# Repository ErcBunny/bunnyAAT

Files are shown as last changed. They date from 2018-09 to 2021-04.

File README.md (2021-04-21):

# bunnyAAT v0.0.2b

* Warning: a senior high school level project.

## PREFACE

* I know it is strange that this repo starts with v0.0.2b. Well, the earlier versions can be found at tieba. And if you read Chinese you'll know more details about this project, which is not necessary at all since the best part (so far) is posted here at github.

## HARDWARE SETUP

* In "hardware" folder you can find autocad blueprints (.dwg) and schematic diagrames.
  
* Read the schematic diagrams and you will know what boards and sensors to buy.
  
* "3mm.dwg" illustrates additional parts needed to complete the structure of the antenna tracker and also the payload adapter for blacksheep  quadcopter airframe, which is shown in "blacksheep.dwg".
  
* "adapter.dwg" is only useful if you want to use the 23dbi MFD antenna. Otherwise you can simply glue your antenna to the moving part.
  
* "base.dwg" shows you what bunnyAAT looks like. Most of its parts are bought online. One possible version of the base can be found here: https://item.taobao.com/item.htm?spm=a1z09.2.0.0.28812e8dhvkkIb&id=37631042726&_u=a2ndlmbi166b.
  
* Also, it is recommended to cover the baro_sensor with a sponge and a reflective surface at the top. By doing this, we can increase sensing accuracy (but only a bit).

## ABOUT SOFTWARE

* There are two apps for android. One of the two is magvar.apk. This app connects automatically to https://www.ngdc.noaa.gov/geomag-web/#declination. By enabling the positioning service the app will return the declination value of your location. The other one is terminal.apk. It is a bluetooth terminal with macro buttons which displays aircraft status and voltage of batteries.
  
* "mwc.ino" should be uploaded into the mwc flight controller board (make sure that your flight controller uses BMP180 and MPU6050, otherwise you need to modify the code). "servo.ino" should be uploaded into another pro mini board. In order to upload sketches you may need the FTDI USB to TTL tool and corresponding driver.
  
* "uno.ino" is for the uno board installed on your aircraft.

## CONFIGURATION

* Change gps refresh rate to 5hz or higher.
  
* Edit macro buttons in the terminal app. '0' must be set as "continue" and '_local declination value_' is recommended to be set as "default". 
  
* Turn your tracker into debug mode by uncommenting the the first line of "mwc.ino" and put your aircraft at the same height as the antenna. Follow the instructions. When you reach the stage of calibrating the mag_sensor, the tracker should spin clockwise. If not, swap the values of LEFT and RIGHT in line 2 and 4. And if the pan servo doesn't stop, modify the STOP value too. The debug mode returns two statements "#define offAlt _value_" and "#define K _value_". Modify the values in line 5 and 6 then comment line 1 and upload. Now you are good to go.
  
* When the the aircraft and AAT are exposed to direct sunlight, the baro_sensors are very likely to be affected. That is, the value returned in debug mode is not accurate anymore. You need to redo debugging or adjust the offAlt value after estimating the error.
  
* The last thing. You may notice that the V_air and V_gnd is really off the track. Therefore, in "mwc.ino" and "uno.ino" you can find "#define offV", which enables you to calibrate the value by hand. For example, if V_gnd is 3.7 displayed in terminal, while its real value is 4.0, then I'll enter "#define offV 0.3 (4.0 - 3.7)".

## CREDITS

* Libraries are very helpful. I saved a lot of time by using them. I'd like to thank contributors who uploaded their libraries.
  
* I don't quite understand how a kalman filter works (just for now), so the code for this part is written by Similar_Fair. Click the link below for more information: https://blog.csdn.net/sunhaobo1996/article/details/53861752.

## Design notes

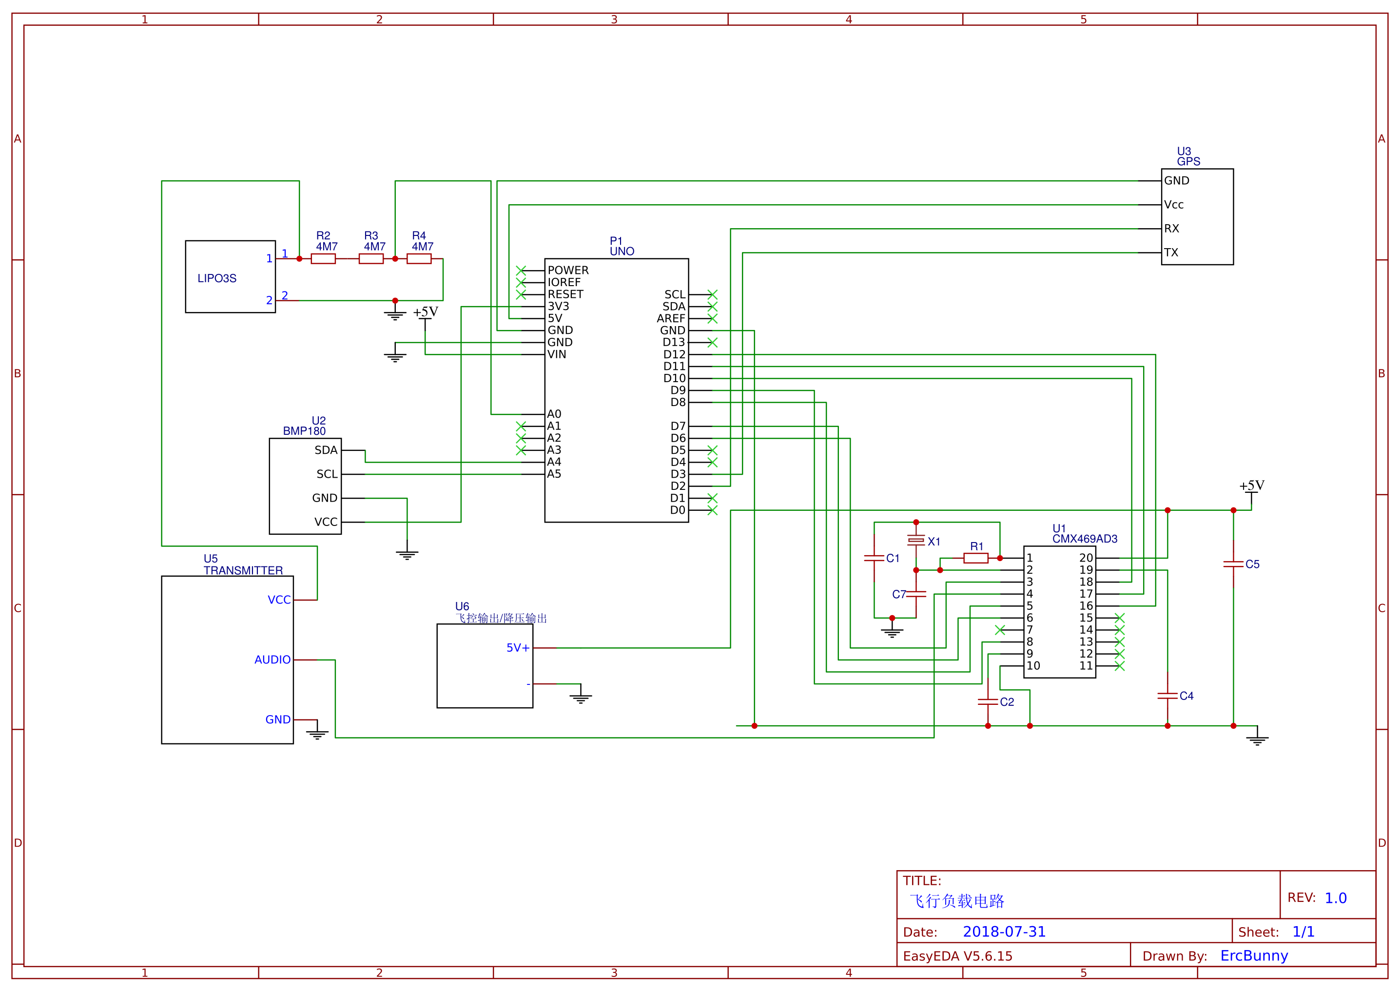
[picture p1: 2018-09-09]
hardware/scheme/aircraft.png

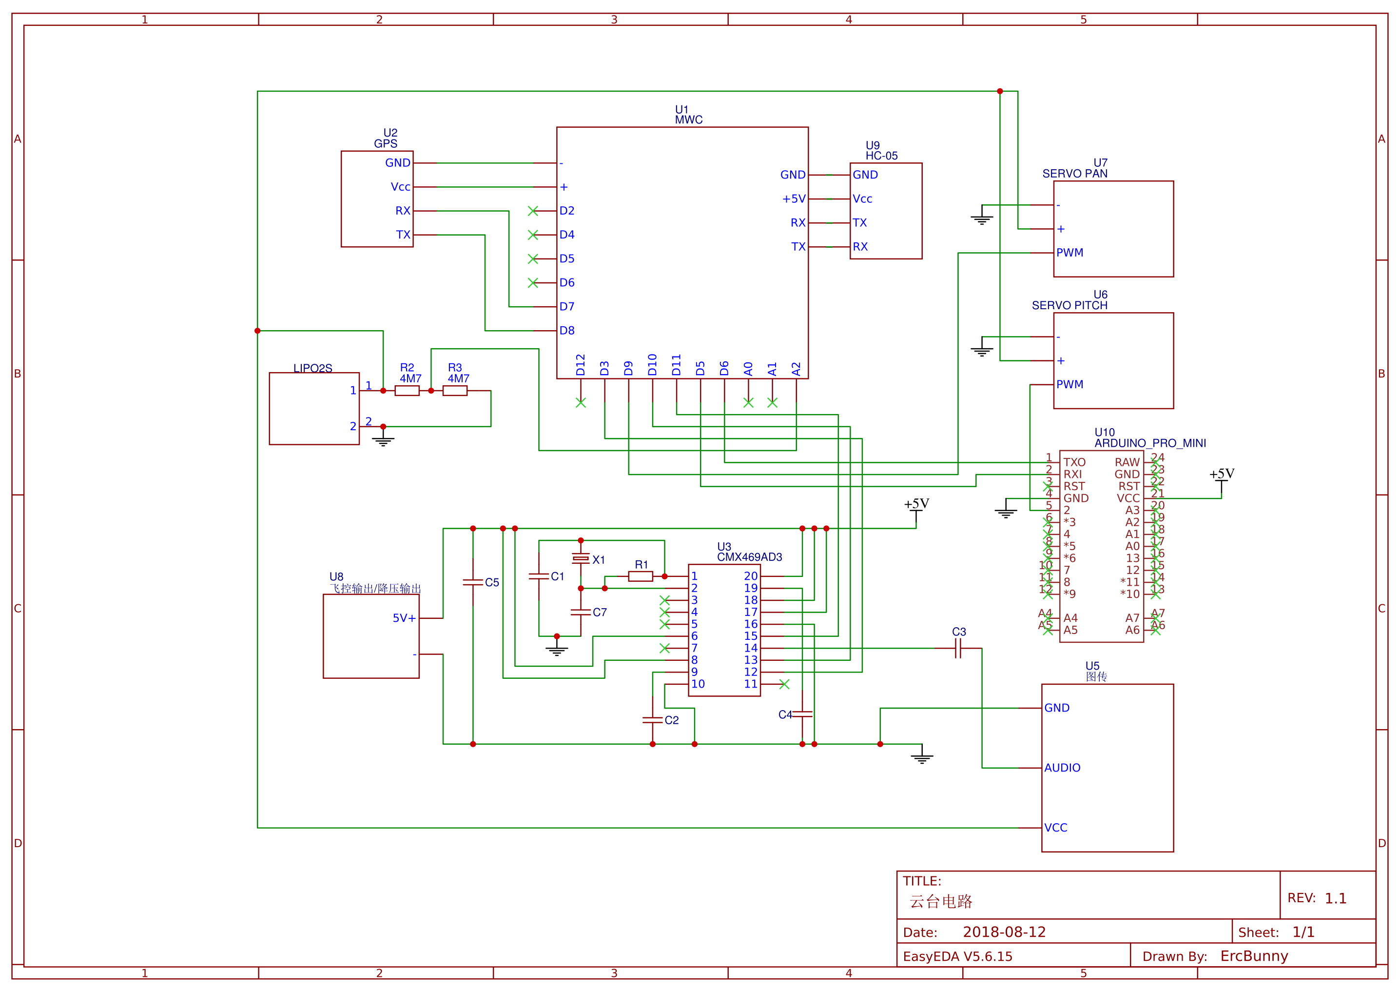
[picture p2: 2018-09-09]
hardware/scheme/aat.png

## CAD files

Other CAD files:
hardware/frame/3mm.dwg
hardware/frame/blacksheep.dwg
hardware/frame/adapter.dwg

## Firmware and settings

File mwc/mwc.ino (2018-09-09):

//#define DEBUG
#define LEFT 180
#define STOP 90
#define RIGHT 0
#define offALT -31.8
#define K 5.5
#define offV 0.11

#include <SoftwareSerial.h>
#include <Wire.h>
#include <Servo.h>
#include <TinyGPS++.h>
#include <HMC5883L.h>
#include <MPU6050.h>
#include <SFE_BMP180.h>

SoftwareSerial gpsCom(8, 7);              //rx,tx
SoftwareSerial pitchCom(6, 5);
TinyGPSPlus gps;
Servo pan;
HMC5883L compass;
MPU6050 mpu;
SFE_BMP180 baro;

int i, m;
int rxdata[135] = {};
int Buffer[120] = {};
char script[29] = {};
float offX, offY, minX, maxX, minY, maxY;
float declination, vt, alt, aim, dst, bat, heading; //angle int->double
double pr, la, lg, angle, baseline;

void setup() {
  Serial.begin(115200);                  //initiate serial com
#ifndef DEBUG
  Serial.println(F("Antenna tracker version 0.0.2 beta by ErcBunny."));  //print info
  Serial.println(F("Initializing sensors..."));
#else
  Serial.println(F("Debug mode. Reading baseline pressure..."));
  Serial.println();
#endif
  mpu.begin(MPU6050_SCALE_2000DPS, MPU6050_RANGE_2G);
  mpu.setI2CMasterModeEnabled(false);
  mpu.setI2CBypassEnabled(true);
  mpu.setSleepEnabled(false);
  compass.begin();
  compass.setRange(HMC5883L_RANGE_1_3GA);
  compass.setMeasurementMode(HMC5883L_CONTINOUS);
  compass.setDataRate(HMC5883L_DATARATE_30HZ);
  compass.setSamples(HMC5883L_SAMPLES_8);
  baro.begin();                                           //setup sensors
  double Pressure, sum = 0;
  for(i = 0; i < 300; i++){
    Pressure = getPressure();
    sum += Pressure;
  }
  baseline = sum / 300;
  Serial.print(F("Done. Baseline pressure (in mb) is "));
  Serial.println(baseline);
  Serial.print(F("Enter declination value (E+|W-): "));   //wait for input
  char a[7] = { 0 };
  i = 0;
  while (1) {
    if (Serial.available()) {
      a[i] = Serial.read();
      i++;
      if (a[i - 1] == 10) {
        break;
      }
    }
  }
  declination = atof(a);
  Serial.println(declination);
  Serial.println(F("Touch continue to start calibration.")); //wait for command
  while (1) {
    if (Serial.available()) {
      i = Serial.read();
      if (i == '0') {
        break;
      }
    }
  }
  calibrate();
  delay(500);
  Serial.println(F("Successful."));
#ifndef DEBUG
  gpsCom.begin(57600);
  Serial.println(F("Waiting for positioning service..."));  //wait till gps is ready
  i = 0;
  while (i == 0) {
    while (gpsCom.available() > 0) {
      if (gps.encode(gpsCom.read()) && gps.location.isUpdated()) {
        i = 1;
      }
    }
  }
  gpsCom.end();
#endif
  pinMode(3, INPUT);        //CLKED DATA 12
  pinMode(10, INPUT);       //CARRIER DETECT 13
  pinMode(11, INPUT);       //RXSYNC 15
#ifndef DEBUG
  Serial.println(F("System setup complete. Touch continue to start using."));
  while (1) {
    if (Serial.available()) {
      i = Serial.read();
      if (i == '0') {
        Serial.println(F("Waiting for data..."));
        break;
      }
    }
  }
  Serial.end();
#endif
}

void loop() {
#ifndef DEBUG
  while (digitalRead(10) == HIGH);
  while (digitalRead(10) == LOW);  //skip incomplete data
  input();                      //store data in rxdata[135]
  check();                      //crc check
  if (m == 0) {
    btod();                     //bin to dec
    extract();                  //store data in variable after checking domain
    calculate();                //calculate dst angle etc.
    output();                   //print info and drive servos
  }
#else
  Serial.begin(115200);
  Serial.println(F("Make sure the aircraft is connected and continue..."));
  while (1) {
    if (Serial.available()) {
      i = Serial.read();
      if (i == '0') {
        break;
      }
    }
  }
  Serial.println(F("Connecting..."));
  Serial.end();
  float sum_alt = 0;
  for (int j = 0; j < 100; j++) {
    while (digitalRead(10) == HIGH);
    while (digitalRead(10) == LOW);
    input();
    check();
    if (m == 0) {
      btod();
      extract();
      calculate();
    }
    sum_alt = alt + sum_alt;                       //sample offalt value 100 times and calculate average
    Serial.begin(115200);
    Serial.print(j);
    Serial.println(F("%"));
    Serial.end();
  }
  Serial.begin(115200);
  Serial.println(F("100%"));
  Serial.print(F("#define offALT "));
  Serial.println(-sum_alt * 0.01);
  Serial.println(F("Touch continue to move on..."));
  while (1) {
    if (Serial.available()) {
      i = Serial.read();
      if (i == '0') {
        break;
      }
    }
  }
  Serial.println(F("Analyzing mechanics..."));
  float heading_temp;
  float sum_k = 0;
  float diff;
  pitchCom.begin(115200);
  pitchCom.println(60);
  pitchCom.end();
  delay(5000);
  pan.attach(9);
  for (i = 1; i < 12; i++) {
    getHeading();
    heading_temp = heading;
    pan.write(RIGHT);
    delay(i * 150);
    pan.write(STOP);
    Serial.print(i * 9.09);
    Serial.println(F("%"));
    delay(1000);
    getHeading();
    if (heading > heading_temp) {
      diff = heading - heading_temp;
    }
    else {
      diff = 360 - (heading_temp - heading);
    }
    sum_k = (i * 150) / diff + sum_k;
    delay(1000);                                    //calculate servo speed constant k*angle(in degree)=delay time
  }                                                 //kâ†‘ delayâ†‘
  pan.detach();
  Serial.println(F("100%"));
  Serial.print(F("#define K "));
  Serial.println(sum_k / 11);
  Serial.println(F("Continue to run debug again... "));
  while (1) {
    if (Serial.available()) {
      i = Serial.read();
      if (i == '0') {
        break;
      }
    }
  }
  Serial.println();
  Serial.end();
#endif
}

void calibrate() {
  Serial.println(F("Calibrating..."));       //autonomously calibrate compass
  pan.attach(9);
  pan.write(RIGHT);
  for (i = 0; i < 1000; i++) {
    Vector mag = compass.readNormalize();
    if (mag.XAxis < minX) minX = mag.XAxis;
    if (mag.XAxis > maxX) maxX = mag.XAxis;
    if (mag.YAxis < minY) minY = mag.YAxis;
    if (mag.YAxis > maxY) maxY = mag.YAxis;
    offX = (maxX + minX) / 2;
    offY = (maxY + minY) / 2;
    delay(2);
  }
  pan.write(STOP);
  delay(500);
  pan.detach();
}

double getPressure() {                       //read barometer
  char status;
  double T, P, p0, a;
  status = baro.startTemperature();
  if (status != 0) {
    delay(status);
    status = baro.getTemperature(T);
    if (status != 0) {
      status = baro.startPressure(3);
      if (status != 0) {
        delay(status);
        status = baro.getPressure(P, T);
        if (status != 0) {
          return(P);
        }
      }
    }
  }
}

void input() {
  int bitBuffer;
  for (i = 0; i < 135; i++) {
    while (digitalRead(11) == HIGH);
    if (digitalRead(3) == HIGH) {
      bitBuffer = 1;
    }
    else {
      bitBuffer = 0;
    }
    rxdata[i] = bitBuffer;
    while (digitalRead(11) == LOW);
  }
}

void check() {
  const int D = 112;
  const int R = 8;
  const int seed[R + 1] = { 1,0,0,1,0,1,1,1,1 };
  int n;
  for (i = 0; i < 10; i++) {
    if (rxdata[i] == 1 && rxdata[i + 1] == 1 && rxdata[i + 2] == 1 && rxdata[i + 3] == 1 && rxdata[i + 4] == 1) {
      break;
    }
  }
  n = i + 5;
  for (i = 0; i < 120; i++) {
    Buffer[i] = rxdata[i + n];
  }                                                   //introns removed
  int cache[R + 1];
  for (i = 0; i < R; i++) {
    cache[i] = seed[i + 1] ^ Buffer[i + 1];
  }
  cache[R] = Buffer[R + 1];
  for (int j = 1; j < D; j++) {                               //112+8-9-1
    if (cache[0] == 0) {
      for (i = 0; i < R; i++) {
        cache[i] = 0 ^ cache[i + 1];
      }
    }
    else {
      for (i = 0; i < R; i++) {
        cache[i] = seed[i + 1] ^ cache[i + 1];
      }
    }
    if (j < D - 1) {
      cache[R] = Buffer[j + R + 1];
    }
    else {
      cache[R] = Buffer[j + R];
    }
  }
  int rem = 0;
  for (i = 0; i < R; i++) {
    rem = rem + cache[i];
  }
  if (rem == 0) {
    m = 0;
  }
  else {
    m = 1;
  }
}

void btod() {
  for (i = 0; i < 28; i++) {
    if (Buffer[i * 4] == 0 && Buffer[i * 4 + 1] == 0 && Buffer[i * 4 + 2] == 0 && Buffer[i * 4 + 3] == 0) {
      script[i] = '0';
    }
    if (Buffer[i * 4] == 0 && Buffer[i * 4 + 1] == 0 && Buffer[i * 4 + 2] == 0 && Buffer[i * 4 + 3] == 1) {
      script[i] = '1';
    }
    if (Buffer[i * 4] == 0 && Buffer[i * 4 + 1] == 0 && Buffer[i * 4 + 2] == 1 && Buffer[i * 4 + 3] == 0) {
      script[i] = '2';
    }
    if (Buffer[i * 4] == 0 && Buffer[i * 4 + 1] == 0 && Buffer[i * 4 + 2] == 1 && Buffer[i * 4 + 3] == 1) {
      script[i] = '3';
    }
    if (Buffer[i * 4] == 0 && Buffer[i * 4 + 1] == 1 && Buffer[i * 4 + 2] == 0 && Buffer[i * 4 + 3] == 0) {
      script[i] = '4';
    }
    if (Buffer[i * 4] == 0 && Buffer[i * 4 + 1] == 1 && Buffer[i * 4 + 2] == 0 && Buffer[i * 4 + 3] == 1) {
      script[i] = '5';
    }
    if (Buffer[i * 4] == 0 && Buffer[i * 4 + 1] == 1 && Buffer[i * 4 + 2] == 1 && Buffer[i * 4 + 3] == 0) {
      script[i] = '6';
    }
    if (Buffer[i * 4] == 0 && Buffer[i * 4 + 1] == 1 && Buffer[i * 4 + 2] == 1 && Buffer[i * 4 + 3] == 1) {
      script[i] = '7';
    }
    if (Buffer[i * 4] == 1 && Buffer[i * 4 + 1] == 0 && Buffer[i * 4 + 2] == 0 && Buffer[i * 4 + 3] == 0) {
      script[i] = '8';
    }
    if (Buffer[i * 4] == 1 && Buffer[i * 4 + 1] == 0 && Buffer[i * 4 + 2] == 0 && Buffer[i * 4 + 3] == 1) {
      script[i] = '9';
    }
  }
}

void extract() {
  int vt_int;
  long pr_long, la_long, lg_long;
  double la_base, lg_base;
  char pr_ch[7] = {};
  char la_ch[10] = {};
  char lg_ch[11] = {};
  char vt_ch[4] = {};
  for (i = 0; i < 6; i++) {
    pr_ch[i] = script[i];
  }
  for (i = 0; i < 8; i++) {
    la_ch[i] = script[i + 7];
  }
  for (i = 0; i < 9; i++) {
    lg_ch[i] = script[i + 16];
  }
  for (i = 0; i < 3; i++) {
    vt_ch[i] = script[i + 25];
  }
  pr_long = atol(pr_ch);
  la_long = atol(la_ch);
  lg_long = atol(lg_ch);
  vt_int = atoi(vt_ch);
  if (pr_long < 110000 && pr_long>89000) {
    pr = pr_long * 0.01;
  }
  vt = vt_int * 0.01;
  if (script[6] == '0') {
    la_long = la_long * (-1);
  }
  if (script[15] == '0') {
    lg_long = lg_long * (-1);
  }
  if (la_long >= -90000000 &&
    la_long <= 90000000 &&
    lg_long >= -180000000 &&
    lg_long <= 180000000
    ) {
    la = la_long * 0.000001;
    lg = lg_long * 0.000001;
  }
}

void calculate() {
#ifndef DEBUG
  int bat_sense = analogRead(A2);
  bat = bat_sense * (5.0 / 1023.0);
  bat += offV;
  alt = baro.altitude(pr, baseline);
  alt = alt + offALT;
  gpsCom.begin(57600);
  i = 0;
  while (i == 0) {
    while (gpsCom.available() > 0) {
      if (gps.encode(gpsCom.read()) && gps.location.isUpdated()) {
        i = 1;
      }
    }
  }
  dst = TinyGPSPlus::distanceBetween(gps.location.lat(), gps.location.lng(), la, lg);
  aim = TinyGPSPlus::courseTo(gps.location.lat(), gps.location.lng(), la, lg);
  gpsCom.end();
  angle = (atan(alt/dst) * 180) / M_PI;       //cancel compensation
#else
  alt = baro.altitude(pr, baseline);
#endif
}

void output() {
  int delta;
  if (angle >= 0) {
    pitchCom.begin(115200);
    pitchCom.println(int(angle));
    pitchCom.end();
  }
  else {
    angle = 0;
    pitchCom.begin(115200);
    pitchCom.println(0);
    pitchCom.end();
  }
  getHeading();
  if (heading < 180) {
    if (aim >= heading + 180 && aim < 360) {
      delta = K * (360 - aim + heading);
      pan.attach(9);
      pan.write(LEFT);
      delay(delta);
      pan.write(STOP);
    }
    else {
      if (aim < heading) {
        delta = K * (heading - aim);
        pan.attach(9);
        pan.write(LEFT);
        delay(delta);
        pan.write(STOP);
      }
      else {
        delta = K * (aim - heading);
        pan.attach(9);
        pan.write(RIGHT);
        delay(delta);
        pan.write(STOP);
      }
    }
  }
  else {
    if (aim >= 0 && aim < heading - 180) {
      delta = K * (360 - heading + aim);
      pan.attach(9);
      pan.write(RIGHT);
      delay(delta);
      pan.write(STOP);
    }
    else {
      if (aim < heading) {
        delta = K * (heading - aim);
        pan.attach(9);
        pan.write(LEFT);
        delay(delta);
        pan.write(STOP);
      }
      else {
        delta = K * (aim - heading);
        pan.attach(9);
        pan.write(RIGHT);
        delay(delta);
        pan.write(STOP);
      }
    }
  }
  delay(100);
  pan.detach();
  Serial.begin(115200);
  Serial.println();
  Serial.print(F("DST:"));
  Serial.print(dst, 1);
  Serial.print(F(" ALT:"));
  Serial.print(alt, 1);
  Serial.print(F(" V_air:"));
  Serial.print(vt, 1);
  Serial.print(F(" V_gnd:"));
  Serial.println(bat, 1);
  Serial.end();
}

void getHeading() {
  float Xh, Yh, roll, pitch, cosRoll, sinRoll, cosPitch, sinPitch;
  Vector mag = compass.readNormalize();
  Vector acc = mpu.readScaledAccel();
  roll = asin(acc.YAxis);
  pitch = asin(-acc.XAxis);
  if (roll > 0.78 || roll<0.78 || pitch>0.78 || pitch < 0.78) {
    cosRoll = cos(roll);
    sinRoll = sin(roll);
    cosPitch = cos(pitch);
    sinPitch = sin(pitch);
    Xh = mag.XAxis * cosPitch + mag.ZAxis * sinPitch;
    Yh = mag.XAxis * sinRoll * sinPitch + mag.YAxis * cosRoll - mag.ZAxis * sinRoll * cosPitch;
  }
  Xh = mag.XAxis - offX;
  Yh = mag.YAxis - offY;
  if (Xh > 0 && Yh > 0) {
    heading = (180 * atan2(Yh, Xh)) / M_PI + declination + 270;
  }
  else if (Xh > 0 && Yh < 0) {
    heading = (180 * atan2(Xh, abs(Yh))) / M_PI + declination + 180;
  }
  else if (Xh < 0 && Yh < 0) {
    heading = (180 * atan2(abs(Yh), abs(Xh))) / M_PI + declination + 90;
  }
  else if (Xh < 0 && Yh > 0) {
    heading = (180 * atan2(abs(Xh), Yh)) / M_PI + declination;
  }
  else if (Xh == 0 && Yh > 0) {
    heading = 0.00;
  }
  else if (Xh == 0 && Yh < 0) {
    heading = 180.00;
  }
  else if (Xh < 0 && Yh == 0) {
    heading = 90.00;
  }
  else if (Xh == 0 && Yh == 0) {
    heading = 270.00;
  }
  if (heading < 0) {
    heading += 360.00;
  }
}

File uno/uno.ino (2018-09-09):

#include <SFE_BMP180.h>
#include <TinyGPS++.h>
#include <SoftwareSerial.h>
#include <Wire.h>

#define offV -0.46

SFE_BMP180 baro;                          //create objects here
TinyGPSPlus gps;
SoftwareSerial gpsCom(3, 2);               //(rx,tx)

int i, vtsense, vt_int;                     //global variables to carry data between functions
double pr, la, lg, vt;
long pr_long, la_long, lg_long;
int raw[120];
int txdata[135] = { 0,0,0,0,0,0,0,0,0,0,1,1,1,1,1 };  //preload introns
char script[29] = {};

void setup() {
  pinMode(8, OUTPUT);                      //txdata 5
  pinMode(6, INPUT);                       //txsync 3
  pinMode(7, OUTPUT);                      //txenable 6
  digitalWrite(7, HIGH);
  pinMode(9, OUTPUT);                      //rxenable 8
  digitalWrite(9, LOW);
  pinMode(10, OUTPUT);                     //clockrate 18
  digitalWrite(10, HIGH);
  pinMode(11, OUTPUT);                     //4.8kselect 17
  digitalWrite(11, HIGH);
  pinMode(12, OUTPUT);                     //1.2k&2.4kselect 16
  digitalWrite(12, LOW);
  pinMode(13, OUTPUT);
  digitalWrite(13, LOW);
  baro.begin();                           //start i2c com
  for(i = 0; i < 1200; i++){
    pr = kalmanFilter(getPressure(), 0.0005, 0.03);
  }
  digitalWrite(13, HIGH);
}

void loop() {
  input();              //get data from senseors
  loadScript();         //form an array to store data
  dtob();               //convert data into binary
  loadRedund();         //add CRC hash bits
  output();             //output txdata to fsk modem
}

void input() {
  vtsense = analogRead(A3);
  vt = vtsense * (5.0 / 1023.0);
  vt += offV;
  pr = kalmanFilter(getPressure(), 0.0005, 0.01);                     //get baro data
  gpsCom.begin(57600);
  i = 0;
  while (i == 0) {
    while (gpsCom.available() > 0) {
      if (gps.encode(gpsCom.read()) && gps.location.isUpdated()) {
        i = 1;
      }
    }
  }
  la = gps.location.lat();
  lg = gps.location.lng();                //get gps data
  gpsCom.end();
}

double getPressure() {                   //measure temperature and then pressure
  char status;
  double T, P, p0, a;
  status = baro.startTemperature();
  if (status != 0) {
    delay(status);
    status = baro.getTemperature(T);
    if (status != 0) {
      status = baro.startPressure(3);
      if (status != 0) {
        delay(status);
        status = baro.getPressure(P, T);
        if (status != 0) {
          return(P);
        }
      }
    }
  }
}

void loadScript() {
  char pr_ch[7] = {};
  char la_ch[10] = {};
  char lg_ch[11] = {};
  char vt_ch[4] = {};
  pr_long = pr * 100;
  la_long = la * 1000000;
  lg_long = lg * 1000000;                     //convert them into long
  vt_int = vt * 100;
  itoa(vt_int, vt_ch, 10);
  ltoa(pr_long, pr_ch, 10);
  ltoa(la_long, la_ch, 10);
  ltoa(lg_long, lg_ch, 10);                 //write them into char arrays
  if (pr < 1000) {                            //add a zero to line digits up
    for (i = 4; i >= 0; i--) {
      pr_ch[i + 1] = pr_ch[i];
    }
    pr_ch[0] = '0';
  }
  if (la < 0) {
    la_ch[0] = '0';
    if (la > -10) {
      for (i = 7; i >= 1; i--) {
        la_ch[i + 1] = la_ch[i];
      }
      la_ch[1] = '0';
    }
  }
  if (la > 0) {                               //sign indicator (1+|0-)
    if (la >= 10) {
      for (i = 7; i >= 0; i--) {
        la_ch[i + 1] = la_ch[i];
      }
      la_ch[0] = '1';
    }
    else {
      for (i = 6; i >= 0; i--) {
        la_ch[i + 2] = la_ch[i];
      }
      la_ch[0] = '1';
      la_ch[1] = '0';
    }
  }
  if (lg < 0) {
    lg_ch[0] = '0';
    if (lg > -10) {
      for (i = 7; i >= 1; i--) {
        lg_ch[i + 2] = lg_ch[i];
      }
      lg_ch[1] = '0';
      lg_ch[2] = '0';
    }
    if (lg > -100 && lg <= -10) {
      for (i = 8; i >= 1; i--) {
        lg_ch[i + 1] = lg_ch[i];
      }
      lg_ch[1] = '0';
    }
  }
  if (lg > 0) {
    if (lg >= 100) {
      for (i = 9; i >= 0; i--) {
        lg_ch[i + 1] = lg_ch[i];
      }
      lg_ch[0] = '1';
    }
    if (lg >= 10 && lg < 100) {
      for (i = 7; i >= 0; i--) {
        lg_ch[i + 2] = lg_ch[i];
      }
      lg_ch[0] = '1';
      lg_ch[1] = '0';
    }
    if (lg < 10) {
      for (i = 6; i >= 0; i--) {
        lg_ch[i + 3] = lg_ch[i];
      }
      lg_ch[0] = '1';
      lg_ch[1] = '0';
      lg_ch[2] = '0';
    }
  }
  for (i = 0; i < 6; i++) {                          //bind separate arrays together as a script
    script[i] = pr_ch[i];
  }
  for (i = 0; i < 9; i++) {
    script[i + 6] = la_ch[i];
  }
  for (i = 0; i < 10; i++) {
    script[i + 15] = lg_ch[i];
  }
  for (i = 0; i < 3; i++) {
    script[i + 25] = vt_ch[i];
  }
}

void dtob() {                                //decimal to binary
  for (i = 0; i < 28; i++) {
    if (script[i] == '0') {
      raw[i * 4] = 0;
      raw[i * 4 + 1] = 0;
      raw[i * 4 + 2] = 0;
      raw[i * 4 + 3] = 0;
    }
    if (script[i] == '1') {
      raw[i * 4] = 0;
      raw[i * 4 + 1] = 0;
      raw[i * 4 + 2] = 0;
      raw[i * 4 + 3] = 1;
    }
    if (script[i] == '2') {
      raw[i * 4] = 0;
      raw[i * 4 + 1] = 0;
      raw[i * 4 + 2] = 1;
      raw[i * 4 + 3] = 0;
    }
    if (script[i] == '3') {
      raw[i * 4] = 0;
      raw[i * 4 + 1] = 0;
      raw[i * 4 + 2] = 1;
      raw[i * 4 + 3] = 1;
    }
    if (script[i] == '4') {
      raw[i * 4] = 0;
      raw[i * 4 + 1] = 1;
      raw[i * 4 + 2] = 0;
      raw[i * 4 + 3] = 0;
    }
    if (script[i] == '5') {
      raw[i * 4] = 0;
      raw[i * 4 + 1] = 1;
      raw[i * 4 + 2] = 0;
      raw[i * 4 + 3] = 1;
    }
    if (script[i] == '6') {
      raw[i * 4] = 0;
      raw[i * 4 + 1] = 1;
      raw[i * 4 + 2] = 1;
      raw[i * 4 + 3] = 0;
    }
    if (script[i] == '7') {
      raw[i * 4] = 0;
      raw[i * 4 + 1] = 1;
      raw[i * 4 + 2] = 1;
      raw[i * 4 + 3] = 1;
    }
    if (script[i] == '8') {
      raw[i * 4] = 1;
      raw[i * 4 + 1] = 0;
      raw[i * 4 + 2] = 0;
      raw[i * 4 + 3] = 0;
    }
    if (script[i] == '9') {
      raw[i * 4] = 1;
      raw[i * 4 + 1] = 0;
      raw[i * 4 + 2] = 0;
      raw[i * 4 + 3] = 1;
    }
  }
}
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
